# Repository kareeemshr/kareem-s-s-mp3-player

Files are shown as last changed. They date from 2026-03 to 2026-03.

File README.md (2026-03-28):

# kareem-s-s-mp3-player
believe it or not its an mp3 player

heres the schematic:

heres the pcb:

heres a 3d render of the pcb:

|part|ammount|value|link|foot print|
|:----|:---:|:----:|----|----|
|Capacitor|4|1uF|https://jlcpcb.com/partdetail/53938-CL05A105KA5NQNC/C52923|0402|
|capacitor|7|10uF|https://jlcpcb.com/partdetail/20411-CL10A106KP8NNNC/C19702|0603|
|capacitor|2|33pF|https://jlcpcb.com/partdetail/1914-0402CG330J500NT/C1562|0402|
|resistor|2|5.1K|https://jlcpcb.com/partdetail/26648-0402WGF5101TCE/C25905|0402|
|resistor|2|1K|https://jlcpcb.com/partdetail/12256-0402WGF1001TCE/C11702|0402|
|resistor|1|10K|https://jlcpcb.com/partdetail/26487-0402WGF1002TCE/C25744|0402|
|resistor|2|33| |0402|
|push button|6||https://jlcpcb.com/partdetail/XUNPU-TS_1088AR02016/C720477|SW_Push_SPST_NO_Alps_SKRK|
|usb-c input|1||https://jlcpcb.com/partdetail/Korean_HropartsElec-TYPE_C_31_M12/C165948|USB_C_Receptacle_HRO_TYPE-C-31-M-12|
|MCU(rp 2040)|1||https://jlcpcb.com/partdetail/RaspberryPi-RP2040/C2040|QFN-56-1EP_7x7mm_P0.4mm_EP3.2x3.2mm|
|flash mem(W25Q16JVSS)|1|16MB|https://jlcpcb.com/partdetail/WinbondElec-W25Q16JVSSIQ/C131025|SOIC-8_5.3x5.3mm_P1.27mm|
|LOD(MCP1700x-330xxTT)|1|5.5V inpt 3.3V outp|https://jlcpcb.com/partdetail/MSKSEMI-MCP1700T_3302E_TT_MS/C20627188|SOT-23|
|crystal|1|12MHZ|https://jlcpcb.com/partdetail/NDK-NX3225GA_12MHZ_STD_CRG2/C481407|Crystal_SMD_3225-4Pin_3.2x2.5mm|
|OLED|1|0.96|https://jlcpcb.com/partdetail/HS-HS96L03W2C03/C5248080|just use a generic conn to act as the i2c pins|
|pcm5102A|1| |https://jlcpcb.com/partdetail/TexasInstruments-PCM5102APW/C1520792|PCM5102A|
|micro sd card reader|1| |https://jlcpcb.com/partdetail/MyAntenna-A_MicroTF_185A/C22467599|Micro_SD_Card_Det_Hirose_DM3AT|
|head_phone_jack|1|https://jlcpcb.com/partdetail/Korean_HropartsElec-PJ_320B3A/C707224|PJ-320B|

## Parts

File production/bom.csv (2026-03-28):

Designator | Footprint | Quantity | Value | LCSC Part #
BOOT | SW_Push_SPST_NO_Alps_SKRK | 1 | BOOTSEL
C1, C2 | 0402 | 2 | 33pF
C10, C11, C12, C13, C15, C16, C20, C25, C29, C3, C6, C7, C8, C9 | 0402 | 14 | 0.1uF
C14, C17, C26, C27, C28 | 0402 | 5 | 1uF
C18, C19, C21, C22, C24, C4, C5 | 0402 | 7 | 10uF
C23 | 0402 | 1 | 0.1unF
J1 | USB_C_Receptacle_HRO_TYPE-C-31-M-12 | 1 | USB_C_Receptacle_USB2.0_14P
J2 | microSD_HC_Hirose_DM3AT-SF-PEJM5 | 1 | Micro_SD_Card_Det_Hirose_DM3AT
J3 | BOOMELE_PJ-320B | 1 | PJ-320B
NEXT | SW_Push_SPST_NO_Alps_SKRK | 1 | next
PLAY/PAUSE | SW_Push_SPST_NO_Alps_SKRK | 1 | play/pause
PREVIOUS | SW_Push_SPST_NO_Alps_SKRK | 1 | previous
R1, R2 | 0402 | 2 | 1K
R10, R11, R12, R13, R14, R3 | 0402 | 6 | 10K
R15, R16 | 0402 | 2 | 27
R4, R5 | 0402 | 2 | 5.1K
R6, R7 | 0402 | 2 | 33
R8, R9 | 0402 | 2 | 4.7K
U1 | QFN-56-1EP_7x7mm_P0.4mm_EP3.2x3.2mm | 1 | RP2040
U2 | SOIC-8_5.3x5.3mm_P1.27mm | 1 | W25Q16JVSS
U3 | SOT-23 | 1 | MCP1700x-330xxTT
U4 | TSSOP-20_4.4x6.5mm_P0.65mm | 1 | PCM5102A
U5 | MODULE_DM-OLED096-636 | 1 | DM-OLED096-636
VOLUME+ | SW_Push_SPST_NO_Alps_SKRK | 1 | volume+
VOLUME- | SW_Push_SPST_NO_Alps_SKRK | 1 | volume-
Y1 | Crystal_SMD_3225-4Pin_3.2x2.5mm | 1 | 12MHz

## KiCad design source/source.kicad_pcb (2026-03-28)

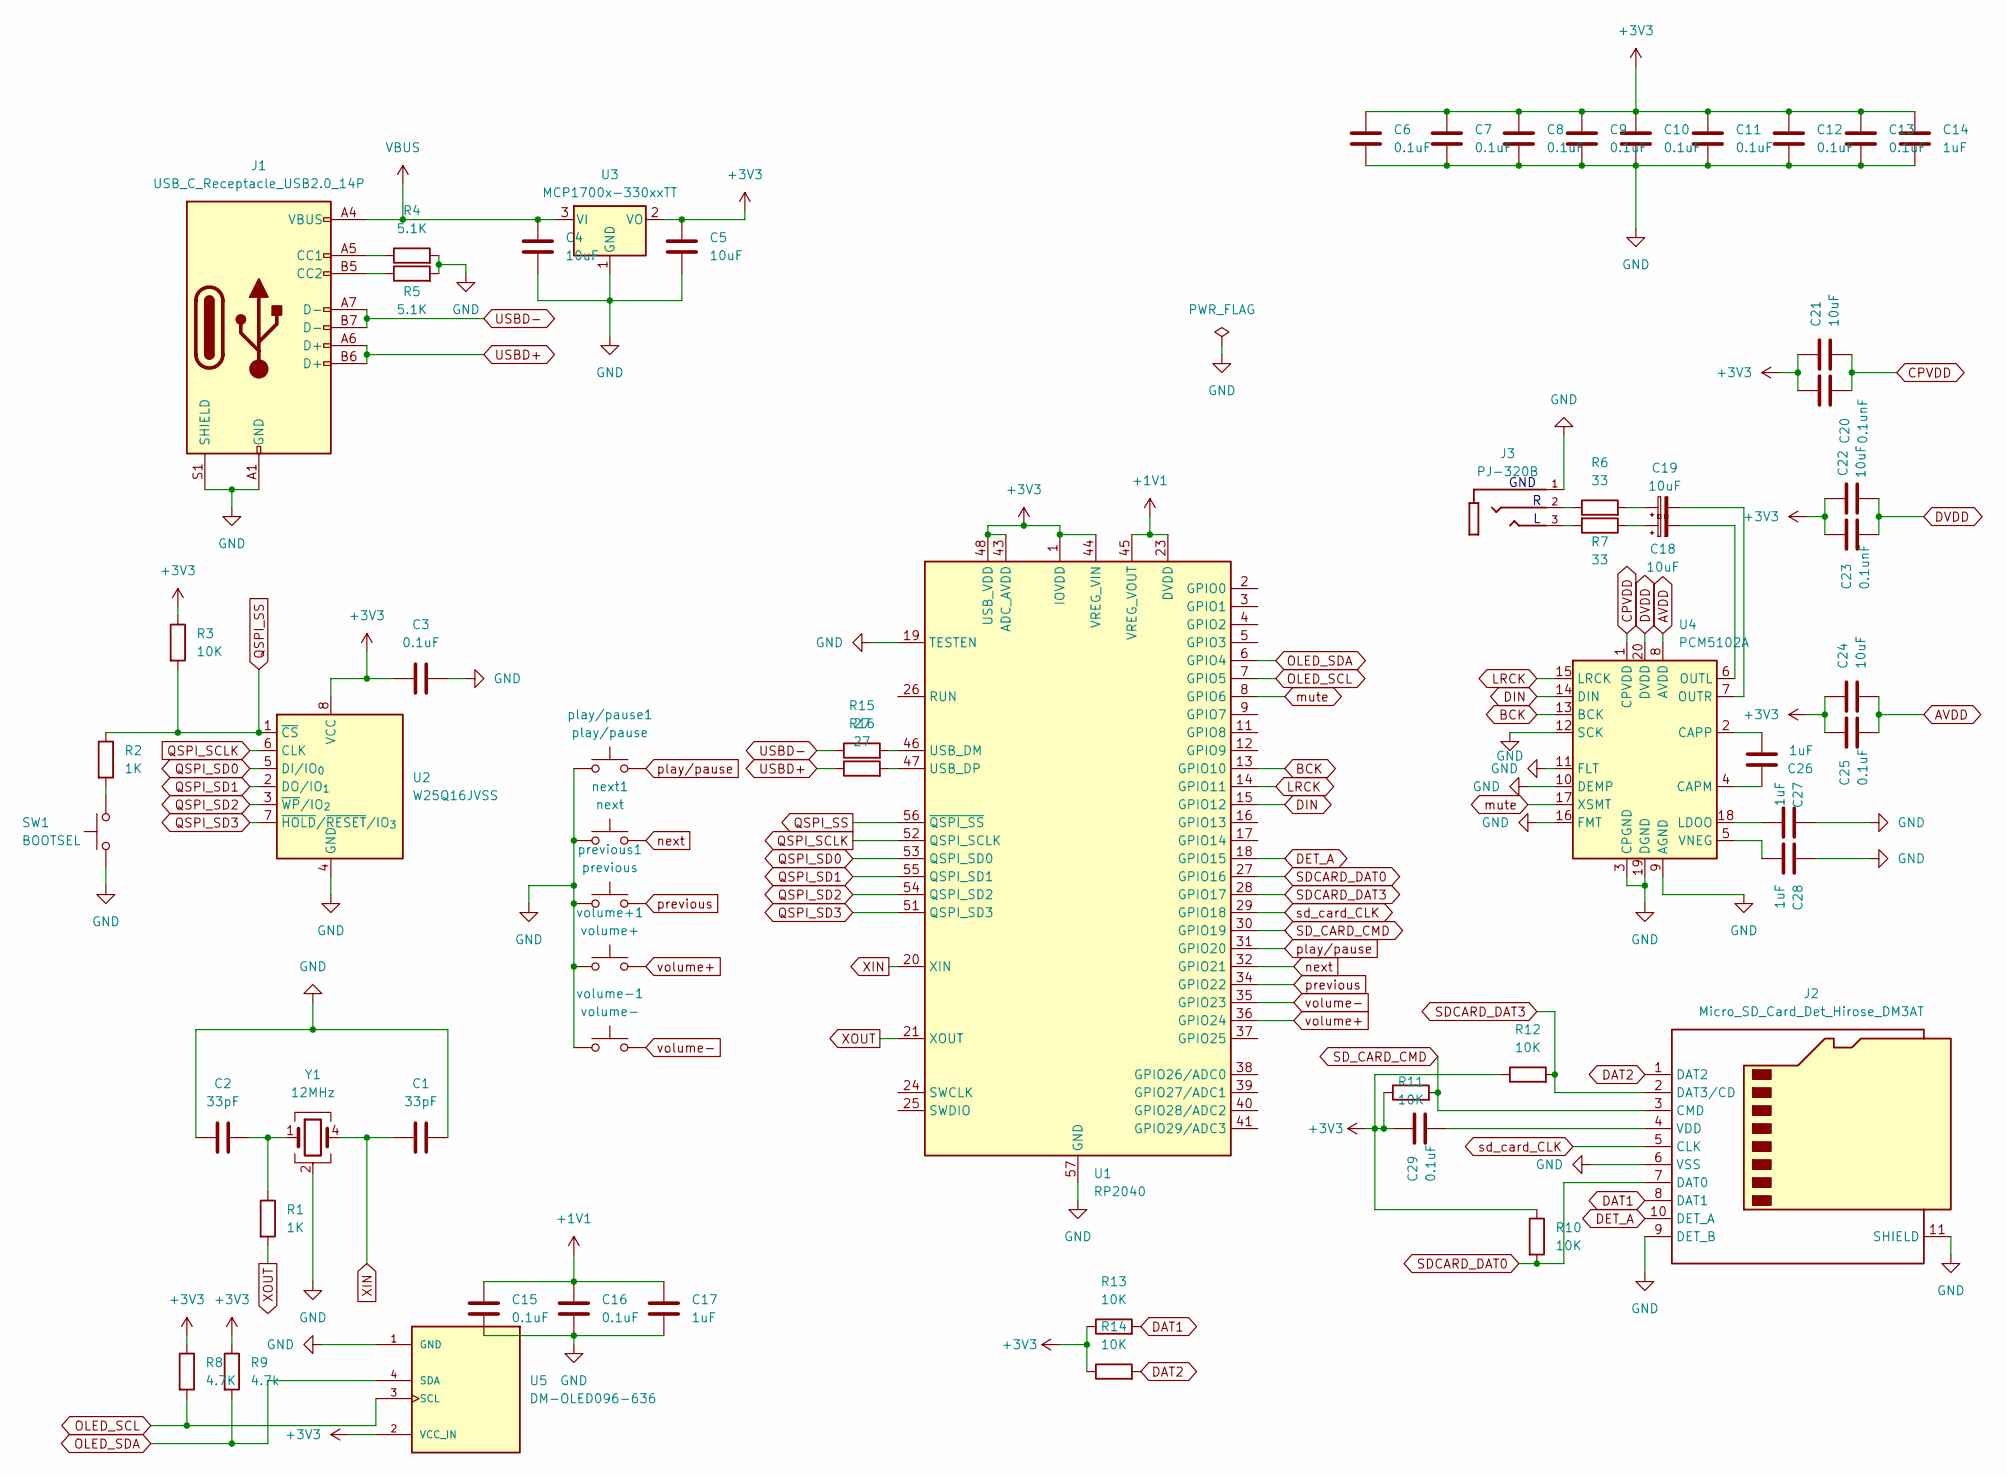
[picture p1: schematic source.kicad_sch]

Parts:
C1, C2: 33pF; C_0402_1005Metric
C3, C6, C7, C8, C9, C10, C11, C12, C13, C15, C16, C25, C29: 0.1uF; C_0402_1005Metric
C4, C5, C18, C19, C21, C22, C24: 10uF; C_0402_1005Metric
C14, C17, C26, C27, C28: 1uF; C_0402_1005Metric
C20, C23: 0.1unF; C_0402_1005Metric
J1: USB_C_Receptacle_USB2.0_14P; USB_C_Receptacle_HRO_TYPE-C-31-M-12
J2: Micro_SD_Card_Det_Hirose_DM3AT; microSD_HC_Hirose_DM3AT-SF-PEJM5
J3: PJ-320B; BOOMELE_PJ-320B
R1, R2: 1K; R_0402_1005Metric
R3, R10, R11, R12, R13, R14: 10K; R_0402_1005Metric
R4, R5: 5.1K; R_0402_1005Metric
R6, R7: 33; R_0402_1005Metric
R8: 4.7K; R_0402_1005Metric
R9: 4.7k; R_0402_1005Metric
R15, R16: 27; R_0402_1005Metric
SW1: BOOTSEL; SW_Push_SPST_NO_Alps_SKRK
U1: RP2040; QFN-56-1EP_7x7mm_P0.4mm_EP3.2x3.2mm
U2: W25Q16JVSS; SOIC-8_5.3x5.3mm_P1.27mm
U3: MCP1700x-330xxTT; SOT-23
U4: PCM5102A; TSSOP-20_4.4x6.5mm_P0.65mm
U5: DM-OLED096-636; MODULE_DM-OLED096-636; PARTREV 2018-09-10
Y1: 12MHz; Crystal_SMD_3225-4Pin_3.2x2.5mm
next1: next; SW_Push_SPST_NO_Alps_SKRK
play/pause1: play/pause; SW_Push_SPST_NO_Alps_SKRK
previous1: previous; SW_Push_SPST_NO_Alps_SKRK
volume+1: volume+; SW_Push_SPST_NO_Alps_SKRK
volume-1: volume-; SW_Push_SPST_NO_Alps_SKRK

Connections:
+1V1: C15.1, C16.1, C17.1, U1.23 (DVDD), U1.45 (VREG_VOUT), U1.50 (DVDD)
+3V3: C3.1, C5.1, C6.1, C7.1, C8.1, C9.1, C10.1, C11.1, C12.1, C13.1, C14.1, C20.1, C21.1, C22.1, C23.1, C24.1, C25.1, C29.1, R3.1, R8.1, R9.1, R10.1, R11.1, R12.1, R13.1, R14.1, U1.1 (IOVDD), U1.10 (IOVDD), U1.22 (IOVDD), U1.33 (IOVDD), U1.42 (IOVDD), U1.43 (ADC_AVDD), U1.44 (VREG_VIN), U1.48 (USB_VDD), U1.49 (IOVDD), U2.8 (VCC), U3.2 (VO), U5.2 (VCC_IN)
AVDD: C24.2, C25.2, U4.8 (AVDD)
BCK: U1.13 (GPIO10), U4.13 (BCK)
CPVDD: C20.2, C21.2, U4.1 (CPVDD)
DAT1: J2.8 (DAT1), R13.2
DAT2: J2.1 (DAT2), R14.2
DET_A: J2.10 (DET_A), U1.18 (GPIO15)
DIN: U1.15 (GPIO12), U4.14 (DIN)
DVDD: C22.2, C23.2, U4.20 (DVDD)
GND: C1.2, C2.1, C3.2, C4.2, C5.2, C6.2, C7.2, C8.2, C9.2, C10.2, C11.2, C12.2, C13.2, C14.2, C15.2, C16.2, C17.2, C27.1, C28.1, J1.A1 (GND), J1.A12 (GND), J1.B1 (GND), J1.B12 (GND), J1.S1 (SHIELD), J2.6 (VSS), J2.9 (DET_B), J2.11 (SHIELD), J3.1, R4.2, R5.2, SW1.1, U1.19 (TESTEN), U1.57 (GND), U2.4 (GND), U3.1 (GND), U4.3 (CPGND), U4.9 (AGND), U4.10 (DEMP), U4.11 (FLT), U4.12 (SCK), U4.16 (FMT), U4.19 (DGND), U5.1 (GND), Y1.2 (G), Y1.3 (G), next1.1, play/pause1.1, previous1.1, volume+1.1, volume-1.1; also elsewhere on the board
LRCK: U1.14 (GPIO11), U4.15 (LRCK)
unnamed: C2.2, R1.1, Y1.1
unnamed: C18.1, R7.1
unnamed: C19.1, R6.2
unnamed: J1.A5 (CC1), R4.1
unnamed: J1.B5 (CC2), R5.1
unnamed: C29.2, J2.4 (VDD)
unnamed: J3.2, R6.1
unnamed: J3.3, R7.2
unnamed 20: R2.2, SW1.2; also elsewhere on the board
unnamed: R15.2, U1.46 (USB_DM)
unnamed: R16.2, U1.47 (USB_DP)
unnamed: C26.1, U4.4 (CAPM)
unnamed: C26.2, U4.2 (CAPP)
unnamed: C27.2, U4.18 (LDOO)
unnamed: C18.2, U4.6 (OUTL)
unnamed: C19.2, U4.7 (OUTR)
unnamed: C28.2, U4.5 (VNEG)
OLED_SCL: R8.2, U1.7 (GPIO5), U5.3 (SCL)
OLED_SDA: R9.2, U1.6 (GPIO4), U5.4 (SDA)
QSPI_SCLK: U1.52 (QSPI_SCLK), U2.6 (CLK)
QSPI_SD0: U1.53 (QSPI_SD0), U2.5 (DI/IO_{0})
QSPI_SD1: U1.55 (QSPI_SD1), U2.2 (DO/IO_{1})
QSPI_SD2: U1.54 (QSPI_SD2), U2.3 (~WP/IO_{2})
QSPI_SD3: U1.51 (QSPI_SD3), U2.7 (~HOLD/~RESET/IO_{3})
QSPI_SS: R2.1, R3.2, U1.56 (~QSPI_SS), U2.1 (~CS)
SDCARD_DAT0: J2.7 (DAT0), R10.2, U1.27 (GPIO16)
SDCARD_DAT3: J2.2 (DAT3/CD), R12.2, U1.28 (GPIO17)
SD_CARD_CMD: J2.3 (CMD), R11.2, U1.30 (GPIO19)
USBD+: J1.A6 (D+), J1.B6 (D+), R16.1
USBD-: J1.A7 (D-), J1.B7 (D-), R15.1
VBUS: C4.1, J1.A4 (VBUS), J1.A9 (VBUS), J1.B4 (VBUS), J1.B9 (VBUS), U3.3 (VI)
XIN: C1.1, U1.20 (XIN), Y1.4
XOUT: R1.2, U1.21 (XOUT)
mute: U1.8 (GPIO6), U4.17 (XSMT)
next: U1.32 (GPIO21), next1.2; also elsewhere on the board
play/pause: U1.31 (GPIO20), play/pause1.2; also elsewhere on the board
previous: U1.34 (GPIO22), previous1.2; also elsewhere on the board
sd_card_CLK: J2.5 (CLK), U1.29 (GPIO18)
volume+: U1.36 (GPIO24), volume+1.2; also elsewhere on the board
volume-: U1.35 (GPIO23), volume-1.2; also elsewhere on the board

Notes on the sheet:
GND

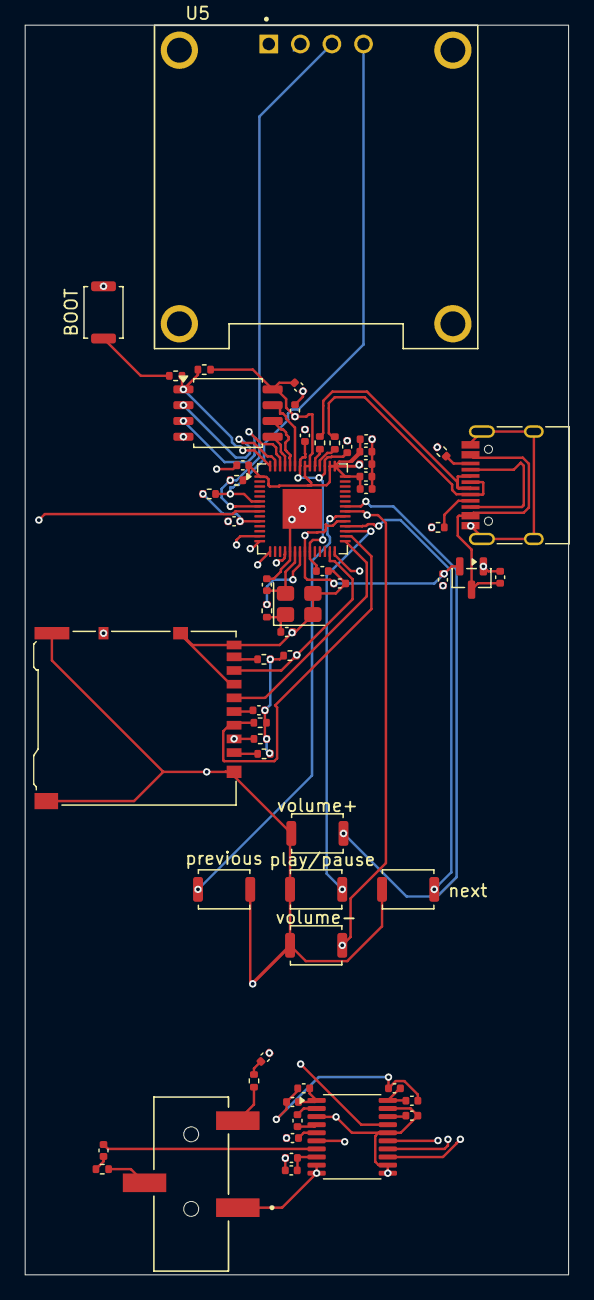
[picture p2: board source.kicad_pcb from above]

Board: 4 copper layers, 43.7 x 100.5 mm, 60 parts (0 on the bottom side), 52 nets.

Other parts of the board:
BOOT: BOOTSEL; SW_Push_SPST_NO_Alps_SKRK
next: next; SW_Push_SPST_NO_Alps_SKRK
play/pause: play/pause; SW_Push_SPST_NO_Alps_SKRK
previous: previous; SW_Push_SPST_NO_Alps_SKRK
volume+: volume+; SW_Push_SPST_NO_Alps_SKRK
volume-: volume-; SW_Push_SPST_NO_Alps_SKRK

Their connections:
GND: BOOT.1, next.1, play/pause.1, previous.1, volume+.1, volume-.1; also elsewhere on the board
unnamed 20: BOOT.2; also elsewhere on the board
next: next.2; also elsewhere on the board
play/pause: play/pause.2; also elsewhere on the board
previous: previous.2; also elsewhere on the board
volume+: volume+.2; also elsewhere on the board
volume-: volume-.2; also elsewhere on the board
